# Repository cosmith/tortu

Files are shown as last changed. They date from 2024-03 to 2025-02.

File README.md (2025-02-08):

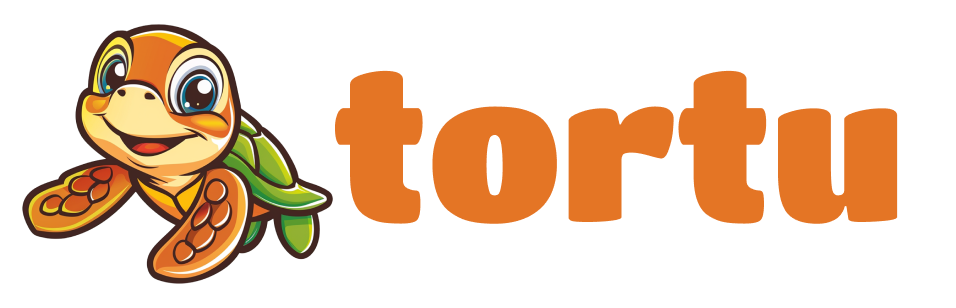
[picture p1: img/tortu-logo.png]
tortu


Tortu is an open source storyteller and music player for kids.

It's also a work in progress :)

Current state:

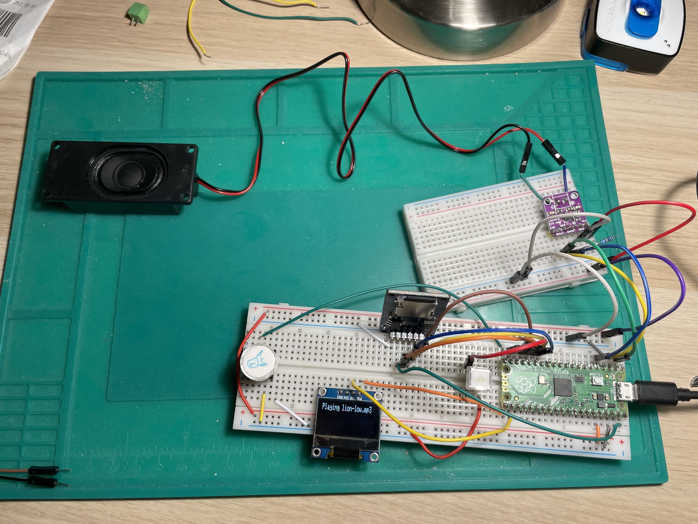
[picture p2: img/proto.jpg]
current state photo


# Todo

## App
- [ ] interface to be able to quickly add a file from youtube/spotify
- [ ] use dall-e or equivalent api to generate cover pictures
- [ ] use any llm to generate a short name for the story
- [ ] use elevenlabs or equivalent api to generate name

## Tortu
- [x] read files from sd card
- [x] play sound
- [x] display something on the screen
- [ ] finalize design
- [x] implement music / story switch
- [x] add volume control
- [x] add 3.5mm jack output

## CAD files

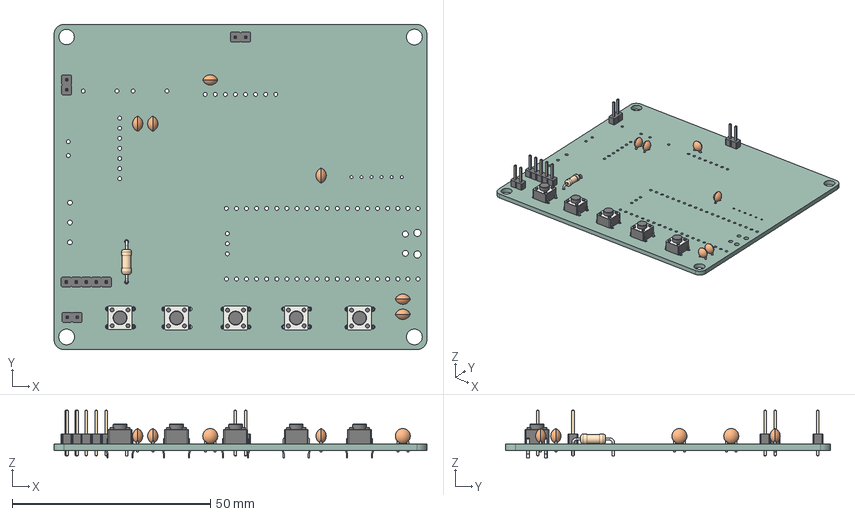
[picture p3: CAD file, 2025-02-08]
circuit/Tortu/Tortu.step
94.0 x 81.9 x 12.0 mm
SW_PUSH_6mm_h5mm x 5
R_Axial_DIN0207_L63mm_D25mm_P1016mm_Horizontal
C_Disc_D38mm_W26mm_P250mm x 6
PinHeader_1x02_P254mm_Vertical x 3
PinHeader_1x05_P254mm_Vertical
Tortu_PCB

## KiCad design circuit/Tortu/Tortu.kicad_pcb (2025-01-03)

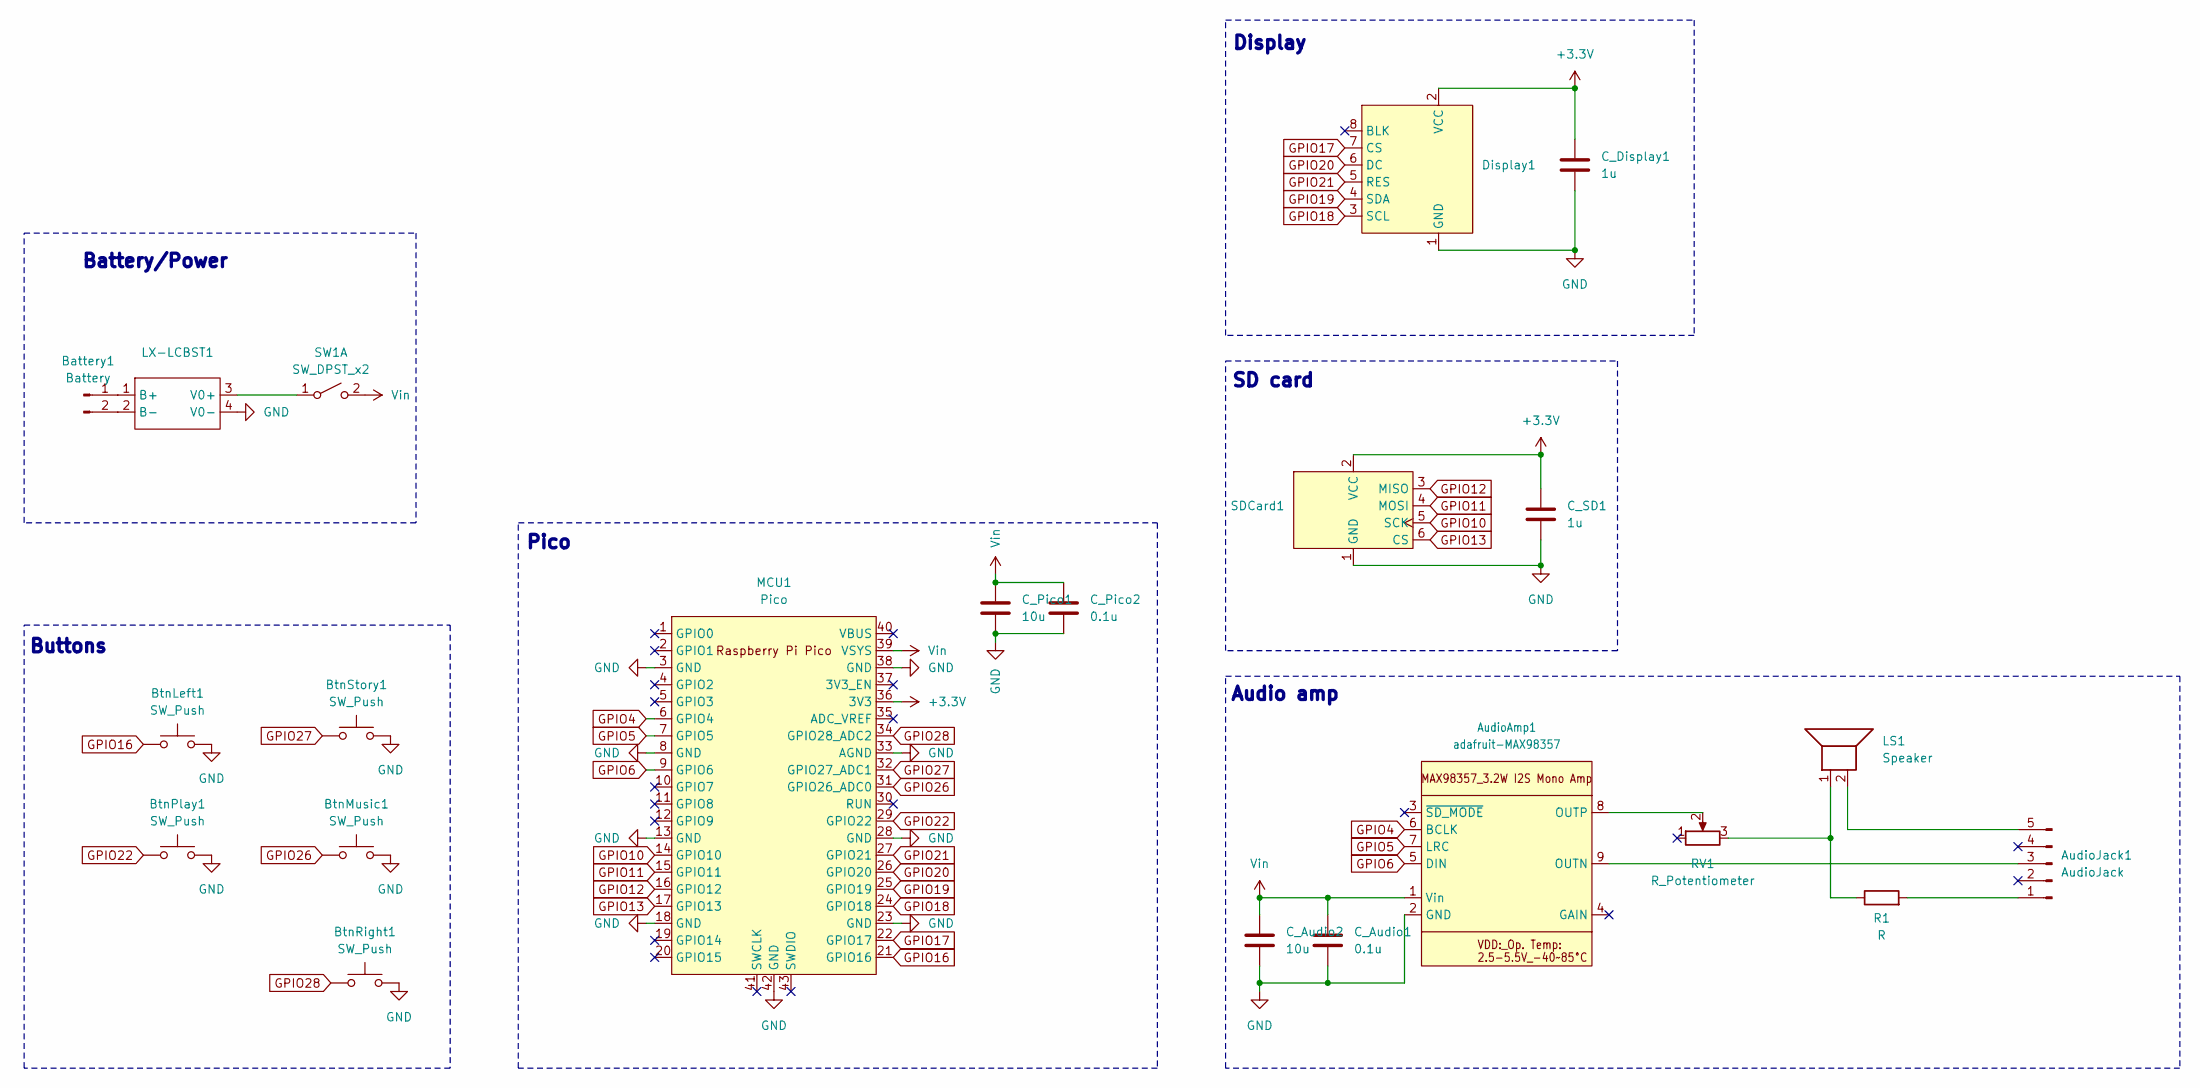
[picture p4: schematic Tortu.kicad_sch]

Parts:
AudioAmp1: adafruit-MAX98357
AudioJack1: AudioJack; PinHeader_1x05_P2.54mm_Vertical
Battery1: Battery; PinHeader_1x02_P2.54mm_Vertical
BtnLeft1: SW_Push; SW_PUSH_6mm_H5mm
BtnMusic1: SW_Push; SW_PUSH_6mm_H5mm
BtnPlay1: SW_Push; SW_PUSH_6mm_H5mm
BtnRight1: SW_Push; SW_PUSH_6mm_H5mm
BtnStory1: SW_Push; SW_PUSH_6mm_H5mm
C_Audio1: 0.1u; C_Disc_D3.8mm_W2.6mm_P2.50mm
C_Audio2: 10u; C_Disc_D3.8mm_W2.6mm_P2.50mm
C_Display1: 1u; C_Disc_D3.8mm_W2.6mm_P2.50mm
C_Pico1: 10u; C_Disc_D3.8mm_W2.6mm_P2.50mm
C_Pico2: 0.1u; C_Disc_D3.8mm_W2.6mm_P2.50mm
C_SD1: 1u; C_Disc_D3.8mm_W2.6mm_P2.50mm
Display1: Display_135x240IPS
LS1: Speaker; PinHeader_1x02_P2.54mm_Vertical
LX-LCBST1: BatteryCharginModule_LX-LCBST
MCU1: Pico; RPi_Pico_SMD_TH
R1: R; R_Axial_DIN0207_L6.3mm_D2.5mm_P10.16mm_Horizontal
RV1: R_Potentiometer; Potentiometer_Alps_RK163_Single_Horizontal
SDCard1: AZDelivery_SDCard
SW1: SW_DPST_x2; PinHeader_1x02_P2.54mm_Vertical

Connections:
+3.3V: C_Display1.1, C_SD1.1, Display1.2 (VCC), MCU1.36 (3V3), SDCard1.2 (VCC)
GND: AudioAmp1.2 (GND), BtnLeft1.2, BtnMusic1.2, BtnPlay1.2, BtnRight1.2, BtnStory1.2, C_Audio1.2, C_Audio2.2, C_Display1.2, C_Pico1.2, C_Pico2.2, C_SD1.2, Display1.1 (GND), LX-LCBST1.4 (V0-), MCU1.3 (GND), MCU1.8 (GND), MCU1.13 (GND), MCU1.18 (GND), MCU1.23 (GND), MCU1.28 (GND), MCU1.33 (AGND), MCU1.38 (GND), MCU1.42 (GND), SDCard1.1 (GND)
GPIO0: MCU1.1 (GPIO0)
GPIO1: MCU1.2 (GPIO1)
GPIO2: MCU1.4 (GPIO2)
GPIO4: AudioAmp1.6 (BCLK), MCU1.6 (GPIO4)
GPIO5: AudioAmp1.7 (LRC), MCU1.7 (GPIO5)
GPIO6: AudioAmp1.5 (DIN), MCU1.9 (GPIO6)
GPIO10: MCU1.14 (GPIO10), SDCard1.5 (SCK)
GPIO11: MCU1.15 (GPIO11), SDCard1.4 (MOSI)
GPIO12: MCU1.16 (GPIO12), SDCard1.3 (MISO)
GPIO13: MCU1.17 (GPIO13), SDCard1.6 (CS)
GPIO16: BtnLeft1.1, MCU1.21 (GPIO16)
GPIO17: Display1.7 (CS), MCU1.22 (GPIO17)
GPIO18: Display1.3 (SCL), MCU1.24 (GPIO18)
GPIO19: Display1.4 (SDA), MCU1.25 (GPIO19)
GPIO20: Display1.6 (DC), MCU1.26 (GPIO20)
GPIO21: Display1.5 (RES), MCU1.27 (GPIO21)
GPIO22: BtnPlay1.1, MCU1.29 (GPIO22)
GPIO26: BtnMusic1.1, MCU1.31 (GPIO26_ADC0)
GPIO27: BtnStory1.1, MCU1.32 (GPIO27_ADC1)
GPIO28: BtnRight1.1, MCU1.34 (GPIO28_ADC2)
unnamed: AudioAmp1.9 (OUTN), AudioJack1.3
unnamed: AudioAmp1.8 (OUTP), RV1.2
unnamed: AudioJack1.1, R1.2
unnamed: AudioJack1.5, LS1.2
unnamed: Battery1.1, LX-LCBST1.1 (B+)
unnamed: Battery1.2, LX-LCBST1.2 (B-)
unnamed: LS1.1, R1.1, RV1.3
unnamed: LX-LCBST1.3 (V0+), SW1.1 (A)
Vin: AudioAmp1.1 (Vin), C_Audio1.1, C_Audio2.1, C_Pico1.1, C_Pico2.1, MCU1.39 (VSYS), SW1.2 (B)

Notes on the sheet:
Buttons
Pico
Battery/Power
Display
Audio amp
SD card

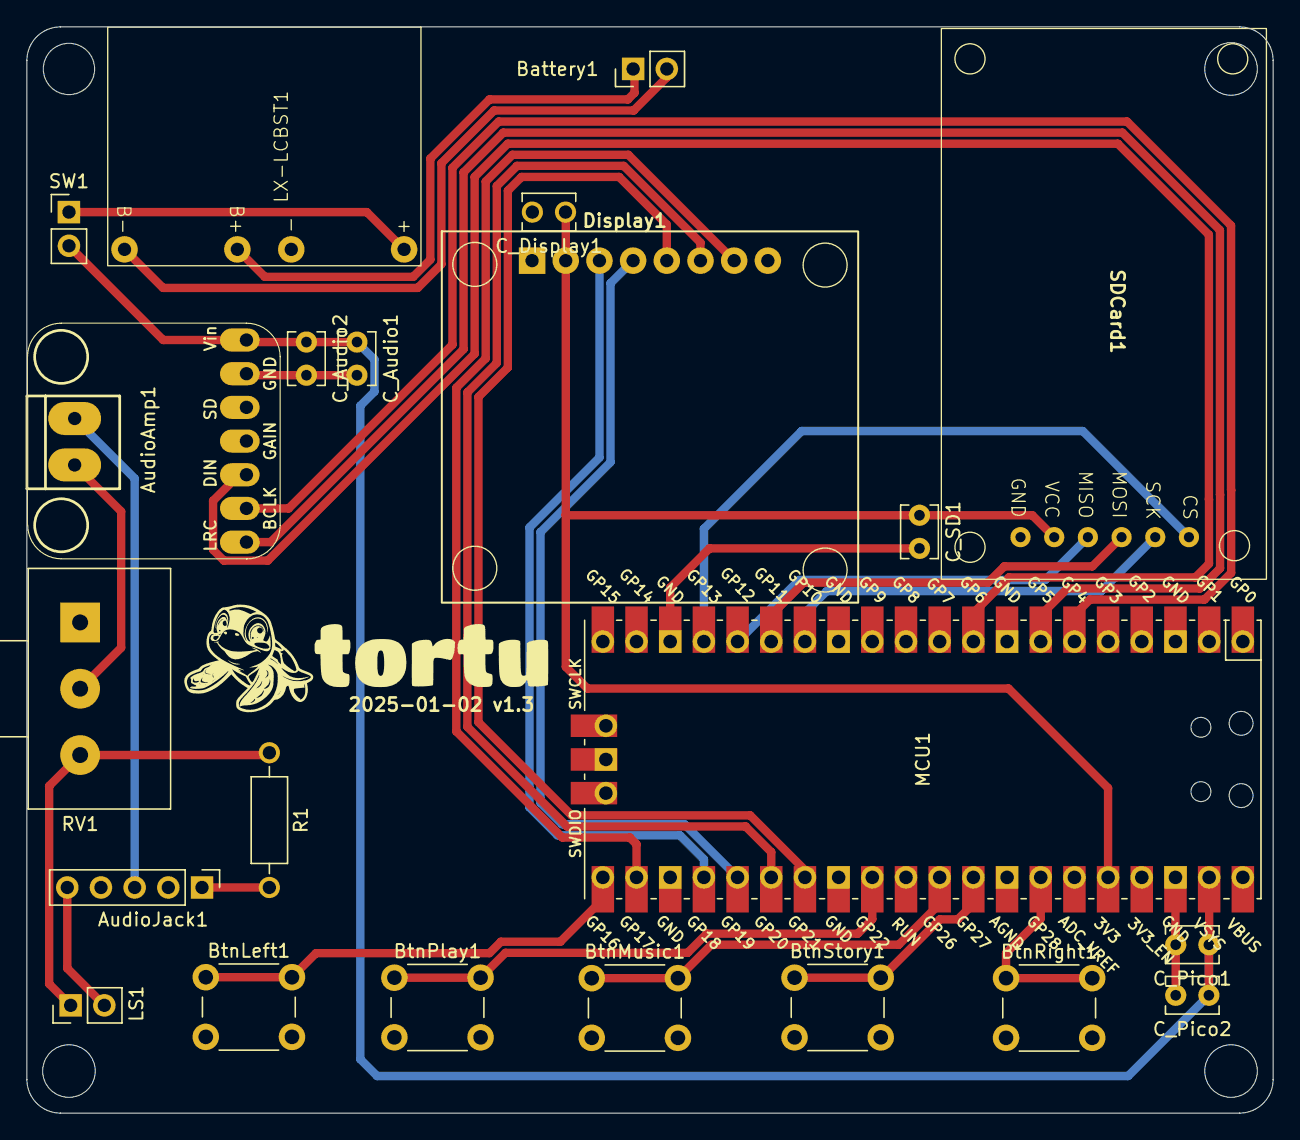
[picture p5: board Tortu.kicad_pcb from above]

Board: 2 copper layers, 94.0 x 81.9 mm, 22 parts (0 on the bottom side), 28 nets.

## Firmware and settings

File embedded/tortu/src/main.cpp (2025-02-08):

#include "SPI.h"
#include <Arduino.h>
#include <TFT_eSPI.h>

#include <SDFS.h>
#include <ArduinoJson.h>

#include <AudioGeneratorMP3.h>
#include <AudioFileSourceFS.h>
#include <AudioFileSourceBuffer.h>
#include <AudioOutputI2S.h>

#include <Display.h>
#include <Button.h>
#include <SDUtils.h>

// SD card
#define SD_SPI_CLK 10
#define SD_SPI_MOSI 11
#define SD_SPI_MISO 12
#define SD_SPI_CS 13

// Test with reduced SPI speed for breadboards.  SD_SCK_MHZ(4) will select
// the highest speed supported by the board that is not over 4 MHz.
// Change SPI_SPEED to SD_SCK_MHZ(50) for best performance.
#define SPI_SPEED SD_SCK_MHZ(10)

// Audio
#define AUDIO_I2S_BCLK 7
#define AUDIO_I2S_LRC 8
#define AUDIO_I2S_DOUT 9

AudioGeneratorMP3 *audioGeneratorMP3;
AudioFileSourceBuffer *audioFileSourceBuffer;
AudioFileSourceFS *audioFileSourceFS;
AudioOutputI2S *audioOutput;

// Buttons
Button buttonLeft(16);
Button buttonPlay(22);
Button buttonMusic(26);
Button buttonStories(27);
Button buttonRight(28);

// State management
State state = INITIALIZING;
State previousState = MENU;
MenuMode menuMode = STORIES;
MenuMode previousMenuMode = STORIES;
int selectedItemIndex = 0;
int previousSelectedItemIndex = 0;
JsonDocument config;

void play(const char *path)
{
    Serial.printf("Playing %s\n", path);
    audioFileSourceFS = new AudioFileSourceFS(SDFS, path);
    audioGeneratorMP3 = new AudioGeneratorMP3();
    audioGeneratorMP3->begin(audioFileSourceFS, audioOutput);
    state = PLAYING;
}

void pause()
{
    Serial.printf("MP3 pause\n");
    state = PAUSED;
}

void stop()
{
    Serial.printf("MP3 stop\n");
    audioGeneratorMP3->stop();
    state = MENU;
}

// String input;
bool readConfig()
{
    File f = SDFS.open("/tortu.json", "r");
    Serial.print(f.size());

    DeserializationError error = deserializeJson(config, f);

    if (error)
    {
        Serial.print("deserializeJson() failed: ");
        Serial.println(error.c_str());
        return false;
    }

    return true;
}

void setup()
{
    Serial.begin(115200);
    delay(5000);
    Serial.println("Serial started");

    // Initialize SD card
    SPI1.setRX(SD_SPI_MISO);
    SPI1.setTX(SD_SPI_MOSI);
    SPI1.setSCK(SD_SPI_CLK);
    SPI1.setCS(SD_SPI_CS);

    Serial.println("SPI pins set");

    SDFSConfig sdFsConfig;
    sdFsConfig.setSPISpeed(SPI_SPEED);
    sdFsConfig.setSPI(SPI1);

    Serial.println("SDFS config set");

    SDFS.setConfig(sdFsConfig);

    bool sdInit = SDFS.begin();
    Serial.println(sdInit ? "SD card initialized" : "SD card initialization failed");

    Dir dir = SDFS.openDir("/");
    Serial.print("Files in /: ");
    Serial.println(dir.next() ? "Yes" : "No");

    // Start the recursive listing from the root directory
    // Only for debugging purposes
    // listDirectoryContents("/");

    bool configOK = readConfig();

    if (!configOK)
    {
        state = ERROR;
        return;
    }

    // Initialize audio I2S interface

    audioOutput = new AudioOutputI2S(44100);
    audioOutput->SetPinout(AUDIO_I2S_BCLK, AUDIO_I2S_LRC, AUDIO_I2S_DOUT);
    audioOutput->SetOutputModeMono(true);
    audioOutput->SetGain(1);

    // Initialize buttons
    buttonLeft.begin();
    buttonPlay.begin();
    buttonMusic.begin();
    buttonStories.begin();
    buttonRight.begin();

    state = MENU;
    Serial.println("\r\nInitialisation done.");
}

void setup1()
{
    initializeDisplay();
    displaySplash();
}

void loop()
{
    bool playPressed = buttonPlay.pressed();
    bool musicPressed = buttonMusic.pressed();
    bool storiesPressed = buttonStories.pressed();
    bool rightPressed = buttonRight.pressed();
    bool leftPressed = buttonLeft.pressed();

    bool playingAudio = false;

    String dir = menuMode == MUSIC ? "music" : "stories";
    JsonObject selectedItem = config[dir][selectedItemIndex];

    switch (state)
    {
    case MENU:
        delay(16);

        if (playPressed)
        {
            String path = "/" + dir + "/" + selectedItem["mp3"].as<String>();
            play(path.c_str());
        }

        if (leftPressed)
        {
            selectedItemIndex = (selectedItemIndex - 1) % config[dir].size();
        }

        if (rightPressed)
        {
            selectedItemIndex = (selectedItemIndex + 1) % config[dir].size();
        }

        if (storiesPressed && menuMode == MUSIC)
        {
            menuMode = STORIES;
            selectedItemIndex = 0;
        }

        if (musicPressed && menuMode == STORIES)
        {
            menuMode = MUSIC;
            selectedItemIndex = 0;
        }

        break;
    case PLAYING:
        playingAudio = audioGeneratorMP3->loop();

        if (!playingAudio)
        {
            Serial.println("Audio finished");
            stop();
        }
        if (playPressed)
        {
            Serial.println("Play pressed, pausing");
            pause();
        }
        if (musicPressed)
        {
            Serial.println("Music pressed, stopping");
            stop();
            if (menuMode == STORIES)
            {
                menuMode = MUSIC;
                selectedItemIndex = 0;
            }
        }
        if (storiesPressed)
        {
            Serial.println("Stories pressed, stopping");
            stop();
            if (menuMode == MUSIC)
            {
                menuMode = STORIES;
                selectedItemIndex = 0;
            }
        }
        if (rightPressed)
        {
            stop();
            selectedItemIndex = (selectedItemIndex + 1) % config[dir].size();
        }
        if (leftPressed)
        {
            stop();
            selectedItemIndex = (selectedItemIndex - 1) % config[dir].size();
        }
        break;
    case PAUSED:
        delay(16);

        if (playPressed)
        {
            state = PLAYING;
        }
        if (musicPressed || storiesPressed)
        {
            Serial.println("Music/stories pressed, stopping");
            stop();
        }
        break;
    }
}

void loop1()
{
    String dir = menuMode == MUSIC ? "music" : "stories";
    JsonObject selectedItem = config[dir][selectedItemIndex];

    if (previousState != state || previousMenuMode != menuMode || previousSelectedItemIndex != selectedItemIndex)
    {
        Serial.printf("State changed from %d to %d\n", previousState, state);
        previousState = state;
        previousMenuMode = menuMode;
        previousSelectedItemIndex = selectedItemIndex;
        displayState(state, menuMode, selectedItem);
    }

    delay(16);
}

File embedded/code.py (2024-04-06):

import os
import adafruit_ssd1306
import audiobusio
import audiomp3
import board
import busio
import sdcardio
import storage
import supervisor
import time
import digitalio

# -----------------------------------------------
# Setup buttons


btn_prev = digitalio.DigitalInOut(board.GP18)
btn_prev.direction = digitalio.Direction.INPUT
btn_prev.pull = digitalio.Pull.UP

btn_play = digitalio.DigitalInOut(board.GP19)
btn_play.direction = digitalio.Direction.INPUT
btn_play.pull = digitalio.Pull.UP

btn_music = digitalio.DigitalInOut(board.GP20)
btn_music.direction = digitalio.Direction.INPUT
btn_music.pull = digitalio.Pull.UP

btn_story = digitalio.DigitalInOut(board.GP21)
btn_story.direction = digitalio.Direction.INPUT
btn_story.pull = digitalio.Pull.UP

btn_next = digitalio.DigitalInOut(board.GP22)
btn_next.direction = digitalio.Direction.INPUT
btn_next.pull = digitalio.Pull.UP

# -----------------------------------------------
# Setup display
i2c = busio.I2C(
    board.GP17,  # SCL
    board.GP16,  # SDA
)
DISPLAY_WIDTH = 128
DISPLAY_HEIGHT = 32
display = adafruit_ssd1306.SSD1306_I2C(DISPLAY_WIDTH, DISPLAY_HEIGHT, i2c)

# -----------------------------------------------
# Setup audio
audio = audiobusio.I2SOut(
    bit_clock=board.GP0,  # Bit clock
    word_select=board.GP1,  # Word select / left right clock
    data=board.GP2,  # data
)


def show_text(text):
    print(text)
    display.fill(0)
    display.text(text, 0, 0, 1)
    display.show()


def setup_sdcard():
    print("here")
    spi = busio.SPI(
        board.GP10,  # clock
        board.GP11,  # MOSI
        board.GP12,  # MISO
    )
    print("spi", spi)
    sd = sdcardio.SDCard(spi, board.GP13, 4000000)
    print("sd", sd)
    vfs = storage.VfsFat(sd)  # type: ignore
    storage.mount(vfs, "/sd")


def get_mp3s(subpath):
    mp3s = sorted(
        [
            f
            for f in os.listdir(f"/sd/{subpath}")
            if f.endswith(".mp3") and not f.startswith(".")
        ]
    )
    return mp3s


def play_mp3s():
    mp3s = get_mp3s("")
    show_text("Found " + str(len(mp3s)) + " mp3s")
    time.sleep(0.5)

    for mp3_filepath in mp3s:
        show_text("Playing " + mp3_filepath)
        filename = "/sd/" + mp3_filepath

        mp3 = audiomp3.MP3Decoder(filename)
        audio.play(mp3)

        last_pause = None

        while audio.playing:
            time.sleep(0.01)
            now = time.monotonic()

            if (
                not btn_play.value
                and audio.paused
                and last_pause
                and now - last_pause > 0.1
            ):
                print(now - last_pause)
                audio.resume()
                show_text("Resumed")
                last_pause = None

            if not btn_play.value and audio.playing:
                audio.pause()
                show_text("Paused")
                last_pause = now
                print(last_pause)

            if not btn_next.value and audio.playing:
                audio.stop()
                show_text("Stopped")
                break

    show_text("Done playing!")


def show_image(img_path):
    with open(img_path, "rb") as f:
        # BMP files begin with a 54-byte header
        header = f.read(54)

        # Get the width and height of the image
        width = int.from_bytes(header[18:22], "little")
        height = int.from_bytes(header[22:26], "little")

        if width > DISPLAY_WIDTH or height > DISPLAY_HEIGHT:
            raise ValueError("Image too large for display")

        # Offset where the pixel data starts
        data_offset = int.from_bytes(header[10:14], "little")

        # Go to start of pixel data
        f.seek(data_offset)

        # Read the pixel data
        pixel_data = f.read()

        # Each byte in the pixel_data corresponds to 8 pixels
        # 1 bit for each pixel, 0 for black, 1 for white
        pixels = []
        for byte in pixel_data:
            for i in range(7, -1, -1):
                pixels.append((byte >> i) & 1)

        # The pixels are read in rows, where each row has width pixels
        # Also note that rows are stored bottom-up
        rows = [pixels[i : i + width] for i in range(0, len(pixels), width)]

        # If you want the rows to be top-down, you can reverse the rows list:
        rows = list(reversed(rows))

    display.fill(0)

    for y, row in enumerate(rows):
        for x, color in enumerate(row):
            display.pixel(x, y, color)
    display.invert(False)
    display.show()


show_text("Hello!")
try:
    setup_sdcard()
    #    show_image("arbre.bmp")
    play_mp3s()

#### buttons debug
#    while True:
#        show_text(f"""prev {btn_prev.value}
# play {btn_play.value}
# music {btn_music.value}
# story {btn_story.value}
# next {btn_next.value}""")
####

except Exception as e:
    show_text(str(e))
    time.sleep(1)
    show_text("reloading in 3..")
    time.sleep(1)
    show_text("reloading in 2..")
    time.sleep(1)
    show_text("reloading in 1..")
    time.sleep(1)
    supervisor.reload()

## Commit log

2024-04-06 Move to Arduino / PlatformIO
    [SoundBox.kicad_sch]
2024-05-04 Add buttons
2025-02-08 Some progress
    [Tortu.step]
